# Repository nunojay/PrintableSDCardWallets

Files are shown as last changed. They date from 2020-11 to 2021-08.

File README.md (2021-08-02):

# 3D Printable SD Card Wallet Generator

OpenSCAD implementation of parametric SD Card wallets, designed with 3D printing in mind. I got inspired to design this after seeing, printing and liking Natalucciu's [SDCardWallet](https://www.thingiverse.com/thing:2995302). I liked it so much that I had to improve upon it to my liking :), by making it as *small / compact* as possible, adding a *wallet close lock* and making *several wallet configurations*. Although inspired by Natalucciu's project, my project was made entirely from the ground up.

Need to hold some Micro SD Cards too? Use a Micro SD Card to SDCard adapter or print [this one here](https://www.thingiverse.com/thing:3520171).

The STL output files for a few practical configurations are included, ready to be sliced and printed.

I exercised the lock mechanism more than 160 times on one of the prints, without any loss of functionality.
The card holding spring will give on the first usage but that's OK, it is expected.

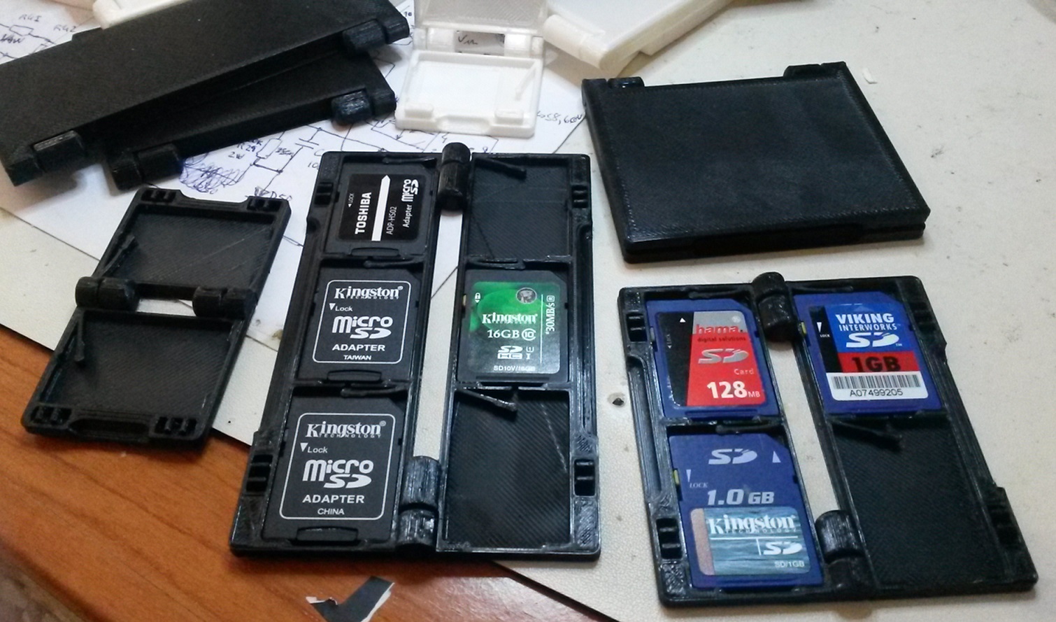
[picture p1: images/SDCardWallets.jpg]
SDCard wallets

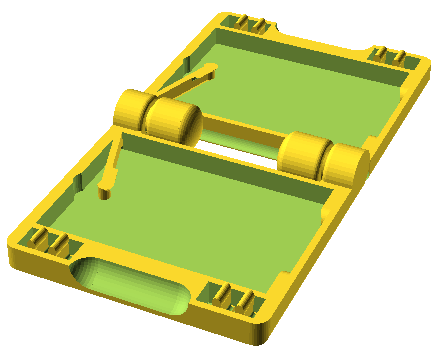
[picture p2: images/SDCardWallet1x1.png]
SDCardWallet1x1

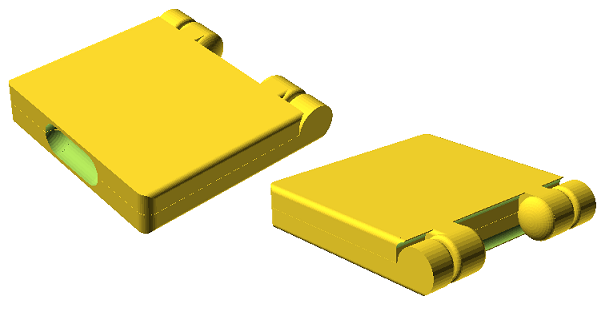
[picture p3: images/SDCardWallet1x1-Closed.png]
SDCardWallet1x1Closed

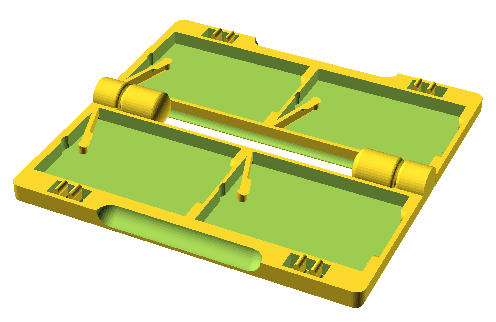
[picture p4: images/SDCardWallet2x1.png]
SDCardWallet2x1

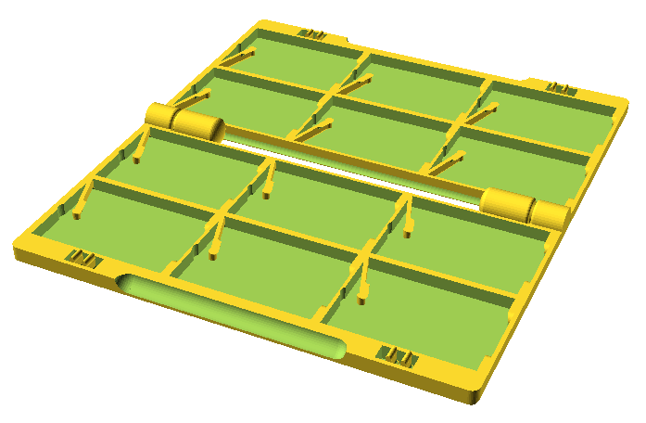
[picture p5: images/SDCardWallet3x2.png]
SDCardWallet3x2


Product development is a set of think - design - print - test iterations.

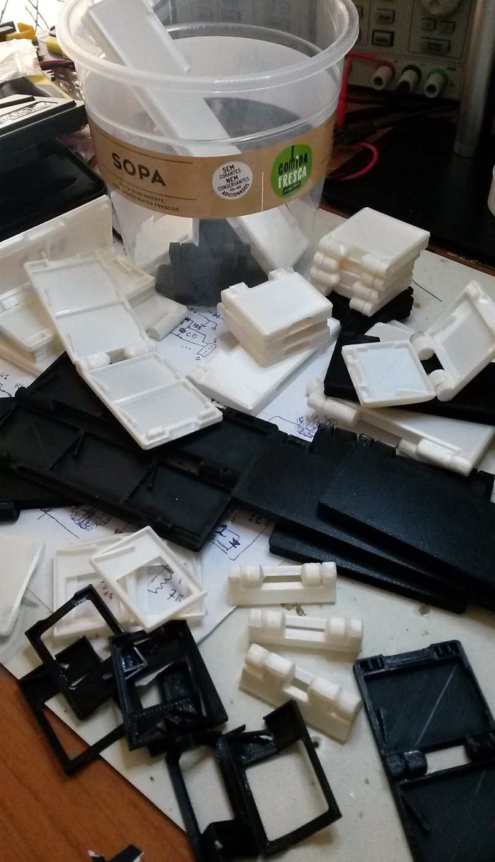
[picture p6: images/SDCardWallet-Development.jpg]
Development leftovers


# Code Structure

The code consists of 3 layers, including 2 libraries that can be used in other projects:

* SDCardHolderLib.scad - Tiny single SD Card holder, featuring spring hold down and 2 opposite side chamfers to keep the card down.
* SDCardWalletLib.scad - Variable configurable SDCard wallet with print in place hinges and keep-closed locks.
* SDCardWalletXxY.scad - Implementation of SD Card wallets of several sizes. They set some configuration variables and use SDCardWalletLib.

If you want a different wallet confguration, create a new _SDCardWalletXxY.scad_ from one of the existing ones and tweak the variables for the configuration you desire. There are more variables that can be tweaked than the ones in the existing _SDCardWalletXxY.scad_ files, take a look at the beggining of file _SDCardWalletLib.scad_ to see what you can change.

# Printing Guidelines

Printing should be done with at least 0.2mm layer height, *no* supports.
Printing parameters depends alot on your slicer, printer and filament. In my tests I have used Ultimakercura 4.6.2, Creality Ender 3 Pro and [Tucab's Fil3D PLA 4032D](https://www.tucab.pt/en/Fil-3D/Filamentos-3D-PLA) filament. I manually optimized Cura settings for a much smaller printing time than the default Cura settings (Standard Quality 0.2mm) for my printer, but it should print just fine on the default Standard Quality.

The wallets are printed already assembled. Upon removal from the printer's bed, you just need to hold it with fingers near/on each hinge and force it slowly to close until it "breaks" and the hinge starts working. The SD Card springs also need to be gently pushed at the tip until they get free from ground.

Have fun :)

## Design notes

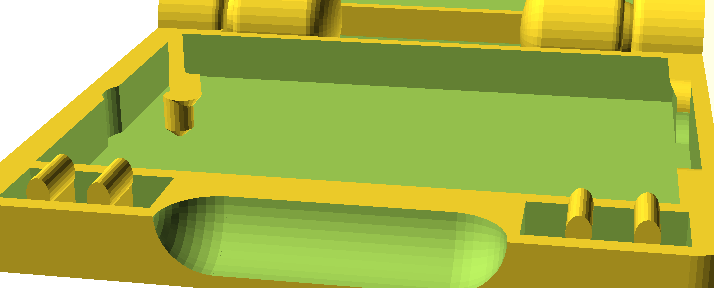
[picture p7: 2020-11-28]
images/SDCardHoldingDetail.png

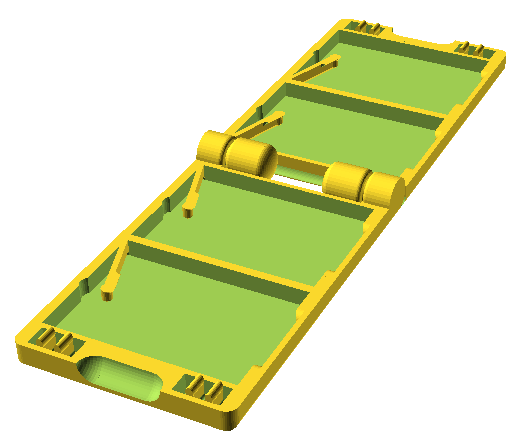
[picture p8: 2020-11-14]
images/SDCardWallet1x2.png

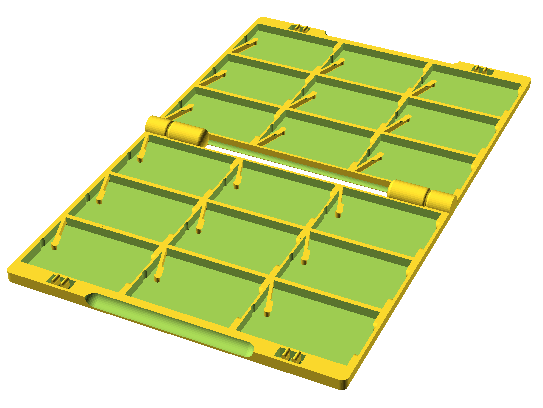
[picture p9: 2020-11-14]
images/SDCardWallet3x3.png

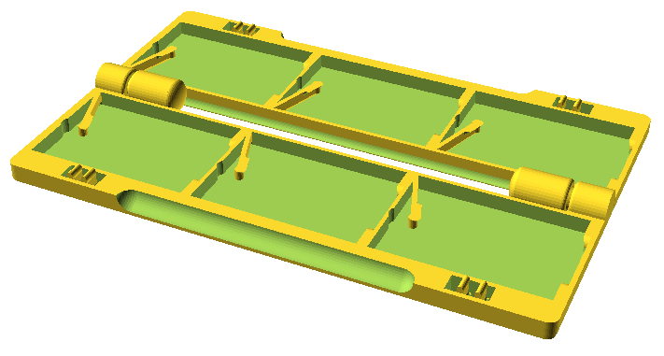
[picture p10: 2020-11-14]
images/SDCardWallet3x1.png

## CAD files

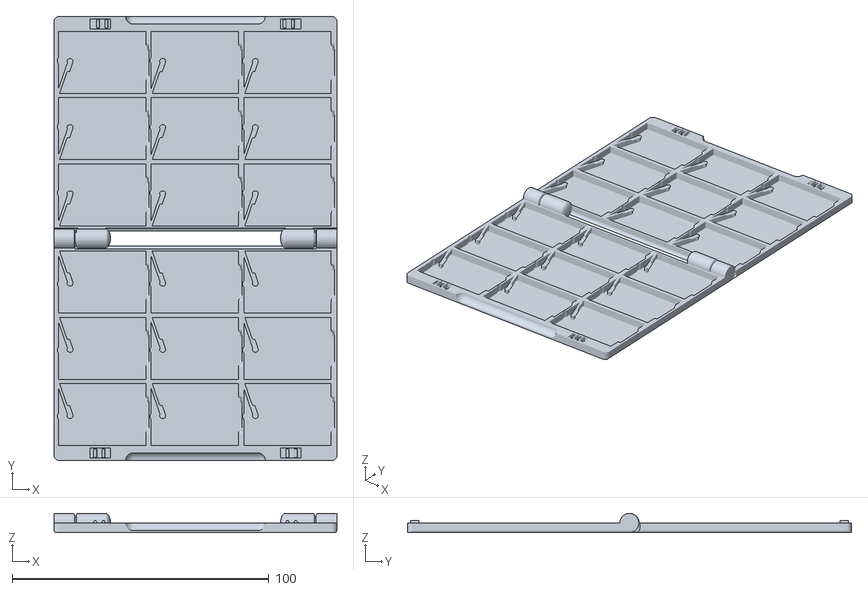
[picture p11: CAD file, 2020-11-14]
official-release-STLs/SDCardWallet3x3.stl
110.3 x 173.1 x 7.42

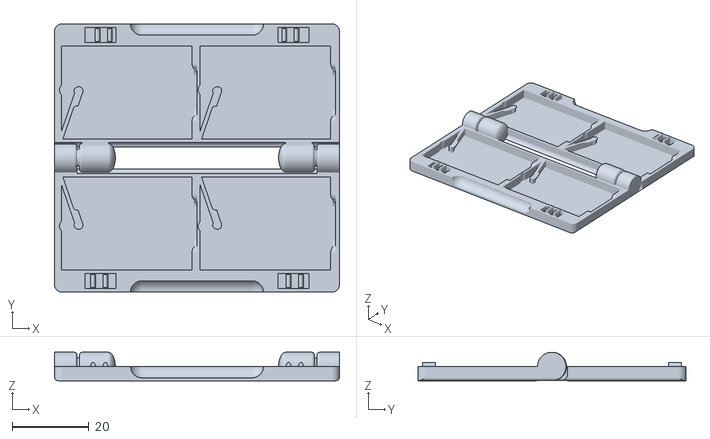
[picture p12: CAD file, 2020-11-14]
official-release-STLs/SDCardWallet2x1.stl
74.2 x 69.9 x 7.42

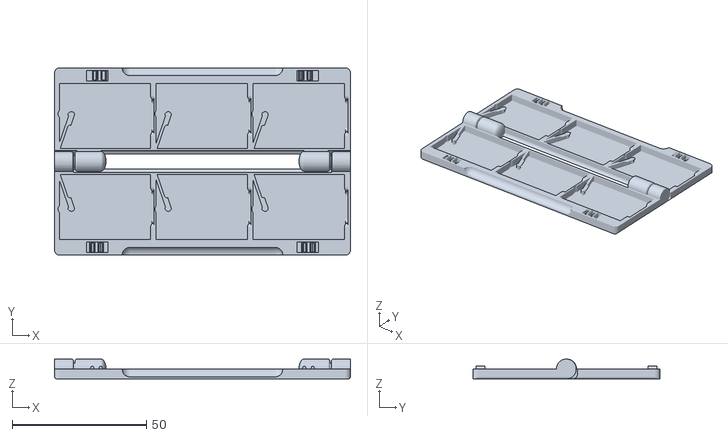
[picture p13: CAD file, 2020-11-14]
official-release-STLs/SDCardWallet3x1.stl
110.3 x 69.9 x 7.42

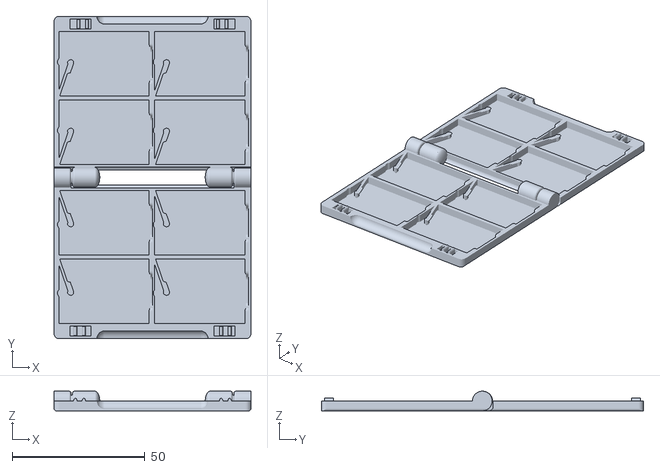
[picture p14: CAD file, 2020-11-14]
official-release-STLs/SDCardWallet2x2.stl
74.2 x 121.5 x 7.42

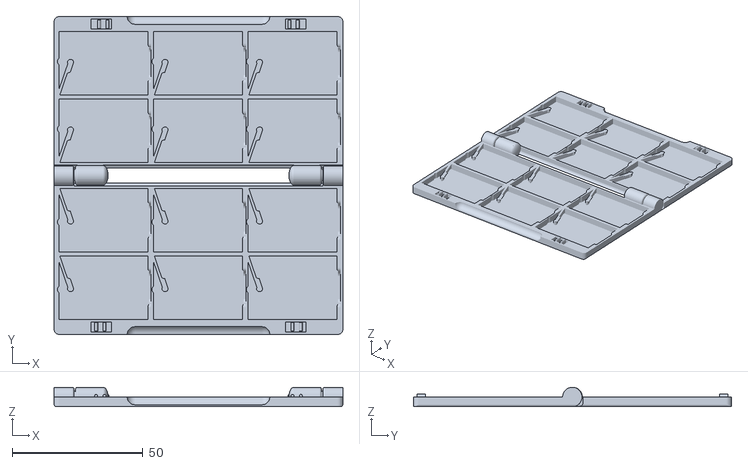
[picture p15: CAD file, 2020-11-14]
official-release-STLs/SDCardWallet3x2.stl
110.3 x 121.5 x 7.42

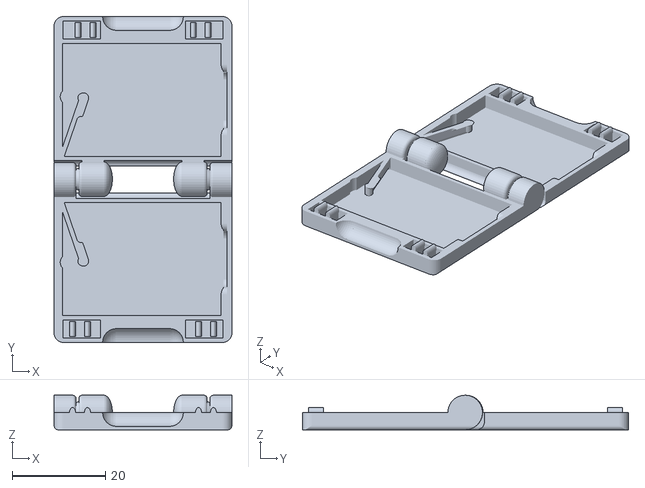
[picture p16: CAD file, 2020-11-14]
official-release-STLs/SDCardWallet1x1.stl
38.1 x 69.9 x 7.42

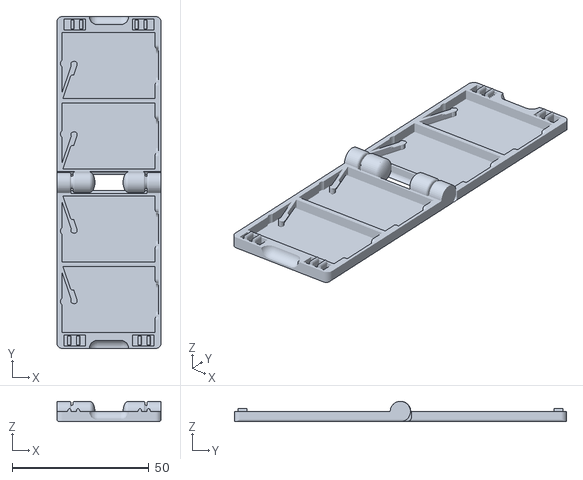
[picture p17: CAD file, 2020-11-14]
official-release-STLs/SDCardWallet1x2.stl
38.1 x 121.5 x 7.42

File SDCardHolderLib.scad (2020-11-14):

////////////////////////////////////////////////////////////////
// SD Card holder
// By Nuno João from https://EmbeddedDreams.com
// Released 2020 under Creative Commons 3.0
//
// This creates a compact SD card holder "box" with spring
// that can secure an SD card. Care was taken in order to
// make it work even when printing with low tolerances.
// See the end of the file for usage.
//

// Parameters. These defaults should cover all normal
// cases and there should be no need to change them
// unless you want to adapt for another card format
// or want ticher walls.

cSDCardDx = 32;
cSDCardDy = 24;
cSDCardDz = 2.1;
cSDCardGap = 0.2;           // Gap between card and holder
cSDCardPlanePad = 0.8;      // Exterior holder wall thickness
cZDetachGap = 0.40;         // Gap from spring to "ground"
cSDCardBackthickness = 0.28;
cSDCardSpringLen = 2.3;     // Distance between card top and holder wall, on spring side
cSpringLen = (cSDCardDy + cSDCardGap) * 0.56;
cSpringThickness = 1.0;
cSpringAngle = 19;

// Precalcs

cSDCardPocketDx = cSDCardDx + cSDCardSpringLen + cSDCardGap;
cSDCardPocketDy = cSDCardDy + cSDCardGap;
cSDCardPocketDz = cSDCardDz * 1.5;
cBlockDx = cSDCardPocketDx + 2 * cSDCardPlanePad;
cBlockDy = cSDCardPocketDy + 2 * cSDCardPlanePad;
cBlockDz = cSDCardPocketDz + cSDCardBackthickness;


function GetSDCardHolderWidth() = cBlockDy;

function GetSDCardHolderLength() = cBlockDx;

function GetSDCardHolderHeight() = cBlockDz;



module semisphere (diameter, fn = 40)  {
    difference()  {
        sphere(d = diameter, $fn = fn);
        d = diameter + 0.0;
        translate([0, 0, diameter/2])
            cube([d, d, d], true);
    }
}


module triprism (leng)  {
    linear_extrude(height = leng)
        polygon(points = [[0,0], [0.5,0], [0,-0.8]],
                paths = [[0,1,2,0]], convexity = 10);
}


// Centered where the 90º corner would be placed.
module RoundChamferMold (radius = 1, width = 1, nonRoundLen = 0)  {
    scale([radius, radius, width])
        difference()  {
            cube([1 - nonRoundLen, 1 - nonRoundLen, 1], center = true);
            translate([(1 - nonRoundLen) / 2, (1 - nonRoundLen) / 2, 0])
                cylinder(h = 1.1, d = 1, center = true, $fn = 40);
        }
}


module Spring (leng, rot, thickness, dz)  {
    ofstZ = 0.1;
    ballPointDiam = thickness * 1.8;
    t2 = thickness / 2;
    rotate([0, 0, 90 - rot])  {
        translate([leng/2 + thickness/2, 0, 0])  {
            // Spring body
            translate([-leng/2, -thickness/2, cZDetachGap*2])
                cube([leng, thickness, dz - cZDetachGap*2]);
            // Top, SDCard holder w/ round chamfer and tip round end 
            difference()  {
                translate([leng/2 - leng/3/2, -ballPointDiam/2, dz - ballPointDiam/2/2-0.09])
                    rotate([90, 90, -90])
                        RoundChamferMold(thickness*2, leng/3, 0.46);
                translate([2, -ballPointDiam/2 - thickness/2 - 0.06, dz*3/4 - 0.2])
                    cylinder(h = dz/4 + 0.4, d = thickness*2, $fn = 25);
            }
            translate([leng/2 + 0.08, -0.35, dz - cZDetachGap*3])
                cylinder(h = cZDetachGap*3, r1 = 0.1, r2 = ballPointDiam/2 + 0.2, $fn = 20);
            translate([leng/2, 0, cZDetachGap*2 - ofstZ])
                cylinder(h = dz - cZDetachGap*2 + ofstZ, d = ballPointDiam, $fn = 20);
            // Conical bottom
            translate([leng/2, 0, ofstZ])
                cylinder(h = cZDetachGap*2 - ofstZ*2, r1 = ofstZ*2, r2 = ballPointDiam/2, $fn = 20);
        }
        // Bottom double side chamfer on the spring body
        translate([0.4, 0, cZDetachGap - 0.1])
            rotate([90, 0, 90])
                linear_extrude(leng)
                    polygon(points = [ [-t2,t2], [t2,t2], [0,-t2*0.5] ]);

        translate([cSDCardPlanePad + 0.3, 0, cZDetachGap*2 - thickness/4])
            rotate([180, 90, 90])
                scale([1.2, 1, 1])
                    RoundChamferMold(thickness*2, thickness, 0.2);
    }
}


module MainBlock (backHole = 1)  {
    difference()  {
        cube([cBlockDx, cBlockDy, cBlockDz]);
        translate([cSDCardPlanePad, cSDCardPlanePad, cSDCardBackthickness + 0.05])
            cube([cSDCardPocketDx, cSDCardPocketDy, cSDCardPocketDz]);

        // Remove a little more material from the base plane
        if (backHole == 1)  {
            cHoleDy = cSDCardPocketDy * 0.8;
            cHoleDx = cSDCardPocketDx * 0.6;
            translate([(cBlockDx - cHoleDx) / 2 * 1.55,
                       (cBlockDy - cHoleDy+1) / 2, -0.1])  {
                // Corner rounded square
                linear_extrude(height = cSDCardBackthickness * 2)
                    offset(r = 1, $fn = 20)
                        square([cHoleDx - 1, cHoleDy - 1]);
            }
        }
    }
}


module SDCard (ofstX = 0, ofstY = 0, zangle = 0, fingerGap = 12, backHole = 1)  {
    translate([ofstX, ofstY, 0])
    rotate([0, 0, zangle])
    translate([-GetSDCardHolderLength()/2, -GetSDCardHolderWidth()/2, 0])  {
        // Spring
        translate([cSDCardPlanePad / 2, 0.1, cSDCardBackthickness + cZDetachGap])
            Spring(cSpringLen, rot = cSpringAngle, thickness = cSpringThickness,
                    dz = cSDCardPocketDz - cZDetachGap);
        difference()  {
            union()  {
                // Holder main block
                MainBlock(backHole);
                // Triangular edge to lock the card in place
                translate([cBlockDx - cSDCardPlanePad, 0, cBlockDz])
                    rotate([90, 0, 180])
                        triprism(cBlockDy);
            }
            // Open a gap for a finger to pull the SD card out
            wallLenMinusFGap = cBlockDy - fingerGap;
            if (fingerGap != 0)  {
                cOffset = 2;
                cOffset2 = cOffset / 2;
                gapCenter = cBlockDy / 2;
                translate([cBlockDx - 1.5, gapCenter,
                            cBlockDz/2 + cSDCardBackthickness + cOffset])
                    rotate([0, 90, 0])
                    linear_extrude(height = 4)
                        offset(r = cOffset, $fn = 40)
                            square([cBlockDz, fingerGap - cOffset*2], center = true);
            }
            endWallCenterDx = cBlockDx - cSDCardPlanePad;
            nonGapLen = wallLenMinusFGap/2 + cSDCardPlanePad;
            chamferRadius = 3.2;
            translate([endWallCenterDx, cBlockDy - wallLenMinusFGap/2, cBlockDz])
                rotate([0,90,0]) RoundChamferMold(chamferRadius, cSDCardPlanePad*2.5);
            translate([endWallCenterDx, wallLenMinusFGap/2, cBlockDz])
                rotate([0,90,180]) RoundChamferMold(chamferRadius, cSDCardPlanePad*2.5);
            // Open a small space on the wall for the spring tip to have a
            // little more travel range.
            cSpringTipPocketDiam = 3.5;
            translate([cSpringTipPocketDiam/2 + cSDCardPlanePad - 0.5,
                       cSpringLen * cos(cSpringAngle) + 0.8,
                       cSDCardPocketDz/2 + cSDCardBackthickness + 0.1])
                cylinder(h = cSDCardPocketDz + 0.1, d = cSpringTipPocketDiam, center = true, $fn = 30);
        }
    }
}


// Draw 2 micro SD cards occupying the area of a single SDCard
// @@TODO
module MicroSDCard ()  {
    cube([cSDCardDx, cSDCardDy, cSDCardDz], true);
}


/// Test stuff

//RoundChamferMold(10);
//rotate([0, 90, 0]) RoundChamferMold(2, 3);

//Spring (cSpringLen, rot = 0, thickness = cSpringThickness, dz = cSDCardPocketDz - cZDetachGap);
SDCard(0, 0, 0);
//SDCard(0, GetSDCardHolderWidth(), 0);
//SDCard(15 + GetSDCardHolderWidth(), 0, 90);
//SDCard(15 + GetSDCardHolderWidth() * 2, 0, 90);

for (col = [-1:1])  {
//    SDCard(0, col * GetSDCardHolderDy(), 0);
}

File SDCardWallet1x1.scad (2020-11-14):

include <SDCardWalletLib.scad>;

//// Overwrite configuration variables from SDCardWalletLib:

cHoldersCfg = [ [0] ];
cFingerOpenWidth = 0.32;    // %/100 of X axis box len
cLockDistFromSide = 1.9;

//// Build it!
Wallet();

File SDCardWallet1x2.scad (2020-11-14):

include <SDCardWalletLib.scad>;

//// Overwrite configuration variables from SDCardWalletLib:

cHoldersCfg = [ [0, 0] ];
cFingerOpenWidth = 0.24;    // %/100 of X axis box len
cLockDistFromSide = 2.5;

//// Build it!
Wallet();

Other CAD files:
SDCardWallet2x1.scad
SDCardWallet2x2.scad
SDCardWallet3x1.scad
SDCardWallet3x2.scad
SDCardWallet3x3.scad
SDCardWalletLib.scad

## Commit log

2020-11-14 Initial release.
    [SDCardHolderLib.scad, SDCardWallet1x1.scad, SDCardWallet1x1.stl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]
2020-11-28 Non functional changes, doc and comments.
    [SDCardWalletLib.scad]
